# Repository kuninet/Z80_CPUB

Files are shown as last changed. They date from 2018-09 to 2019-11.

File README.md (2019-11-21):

# Z80マイコンCPUボード (KZ80-CPUB)

- SBC8080バスにつながるZ80 CPUボード KZ80-CPUB のデータ類です。
  - CPUボード+[SBC8080 SUBルーズキット](https://vintagechips.wordpress.com/2018/06/23/sbc8080-subルーズキット/)などとのセットでコンピューターとして動作します。(単独では動きません)

- 回路図、部品等の詳しい説明を記載したwikiページは以下になります。
  - https://github.com/kuninet/Z80_CPUB/wiki

## ファイル/ディレクトリ

ファイル/ディレクトリの構成は以下のとおりです

|ファイル/ディレクトリ|概要|
|:--|:--|
|KiCAD/PCB/|基板製造用ガーバーファイル等|
|KiCAD/Z80-CPUB.ods|部品一覧表|
|img/Z80-CPUB.pdf|回路図 PDF版|
|KiCAD/Z80-CPUB*.*|KiCADファイル|

## 注意点

- REV1基板はSBC8080ルーズキットと完全互換ではありません。
  - DMAは行なえません。(#BUSREQ/#BUSACKに対応していない)
  - DMAに伴う#IOR/Wや#MEMR/Wのハイインピーダンス対応を実施していません。

## ライセンス

- 本リポジトリのデータは MIT License のもとで公開します。[LICENSE.txt](LICENSE.txt)を参照して下さい。

## 参照

[電脳伝説:SBC8080ルーズキット](https://vintagechips.wordpress.com/2018/06/24/sbc8080-cpu%E3%83%AB%E3%83%BC%E3%82%BA%E3%82%AD%E3%83%83%E3%83%88/)

[SBC8080 SUBボードへつなぐZ80 CPUボードの作成](https://kuninet.org/2018/08/01/sbc8080-subボードへつなぐz80-cpuボードの作成/)

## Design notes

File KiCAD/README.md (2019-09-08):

# Z80 CPUボード

## 概要

- SBC8080ルーズキットのバス(SBC8080バスと呼称)につながるZ80 CPUボードのKiCADデータです。

## ファイル/ディレクトリ

ファイル/ディレクトリの構成は以下のとおりです

|ファイル/ディレクトリ|概要|
|:--|:--|
|PCB/|基板製造用ガーバーファイル等|
|Z80-CPUB.ods|部品一覧表|
|Z80-CPUB.pdf|回路図 PDF版|
|Z80-CPUB*.*|KiCADファイル|

## 注意点

- REV1基板は、SBC8080ルーズキットと完全互換ではありません。
  - DMAは行なえません。(#BUSREQ/#BUSACKに対応していない)
  - DMAに伴う#IOR/Wや#MEMR/Wのハイインピーダンス対応を実施していません。

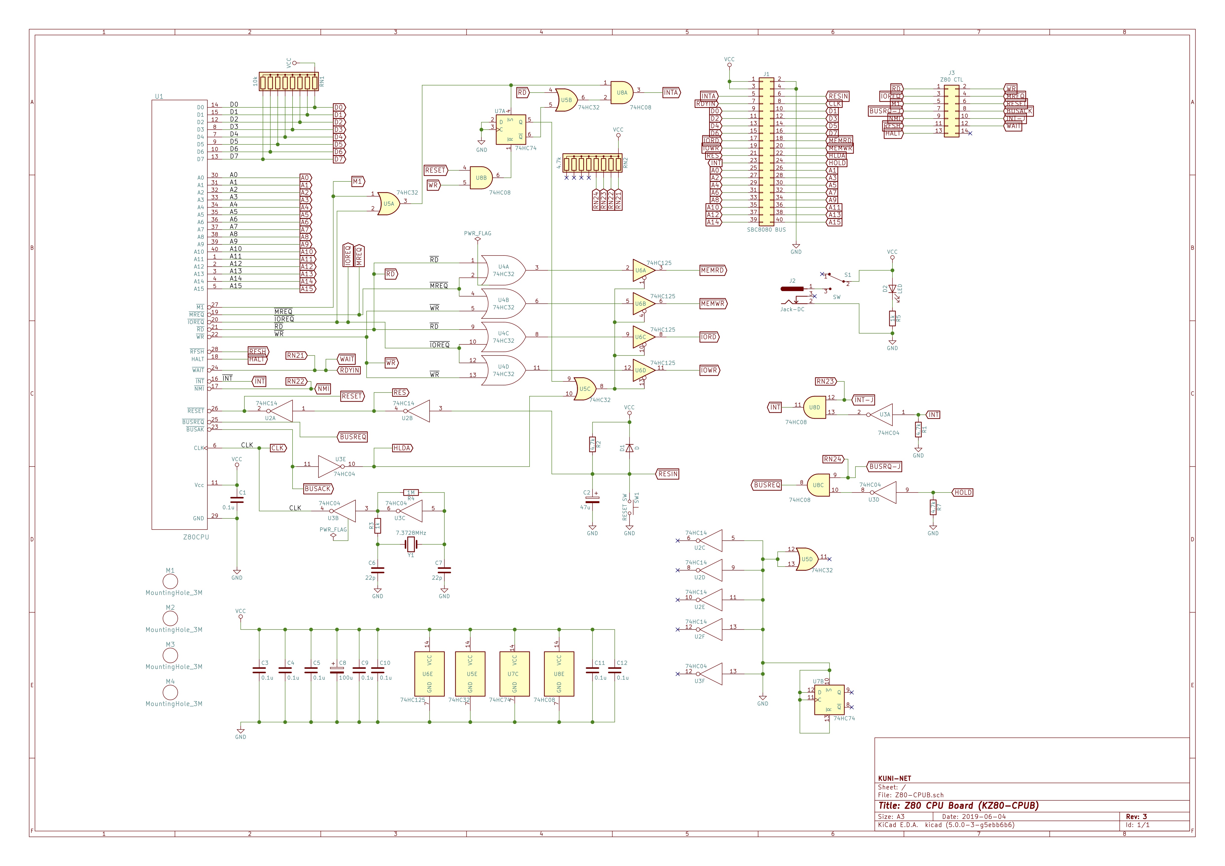
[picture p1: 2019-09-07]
img/Z80-CPUB.jpg

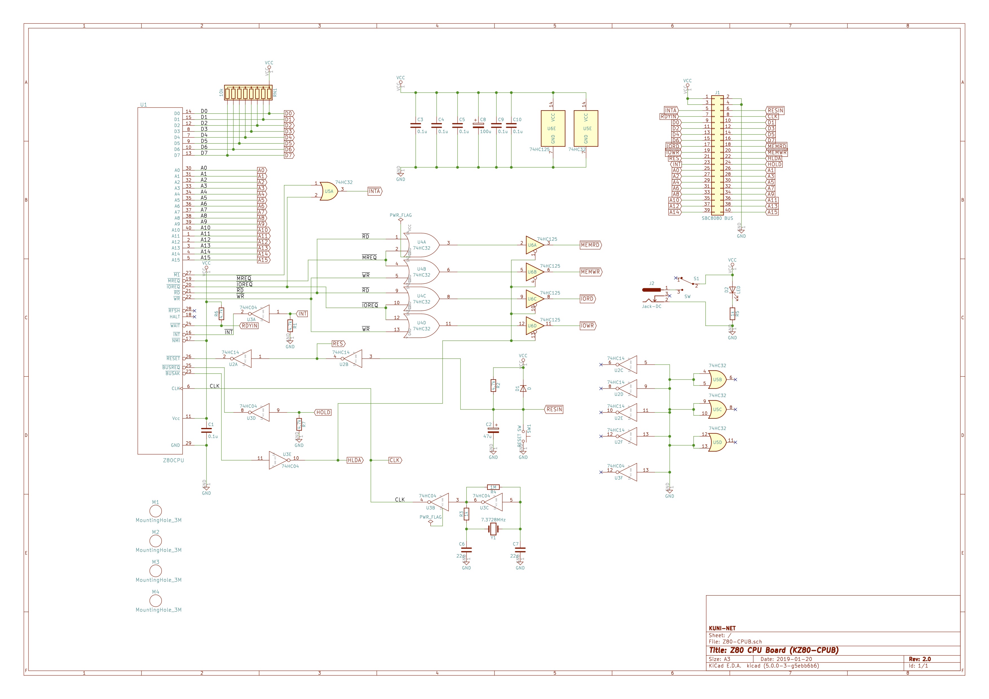
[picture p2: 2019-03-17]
img/Z80-CPUB-REV2.jpg

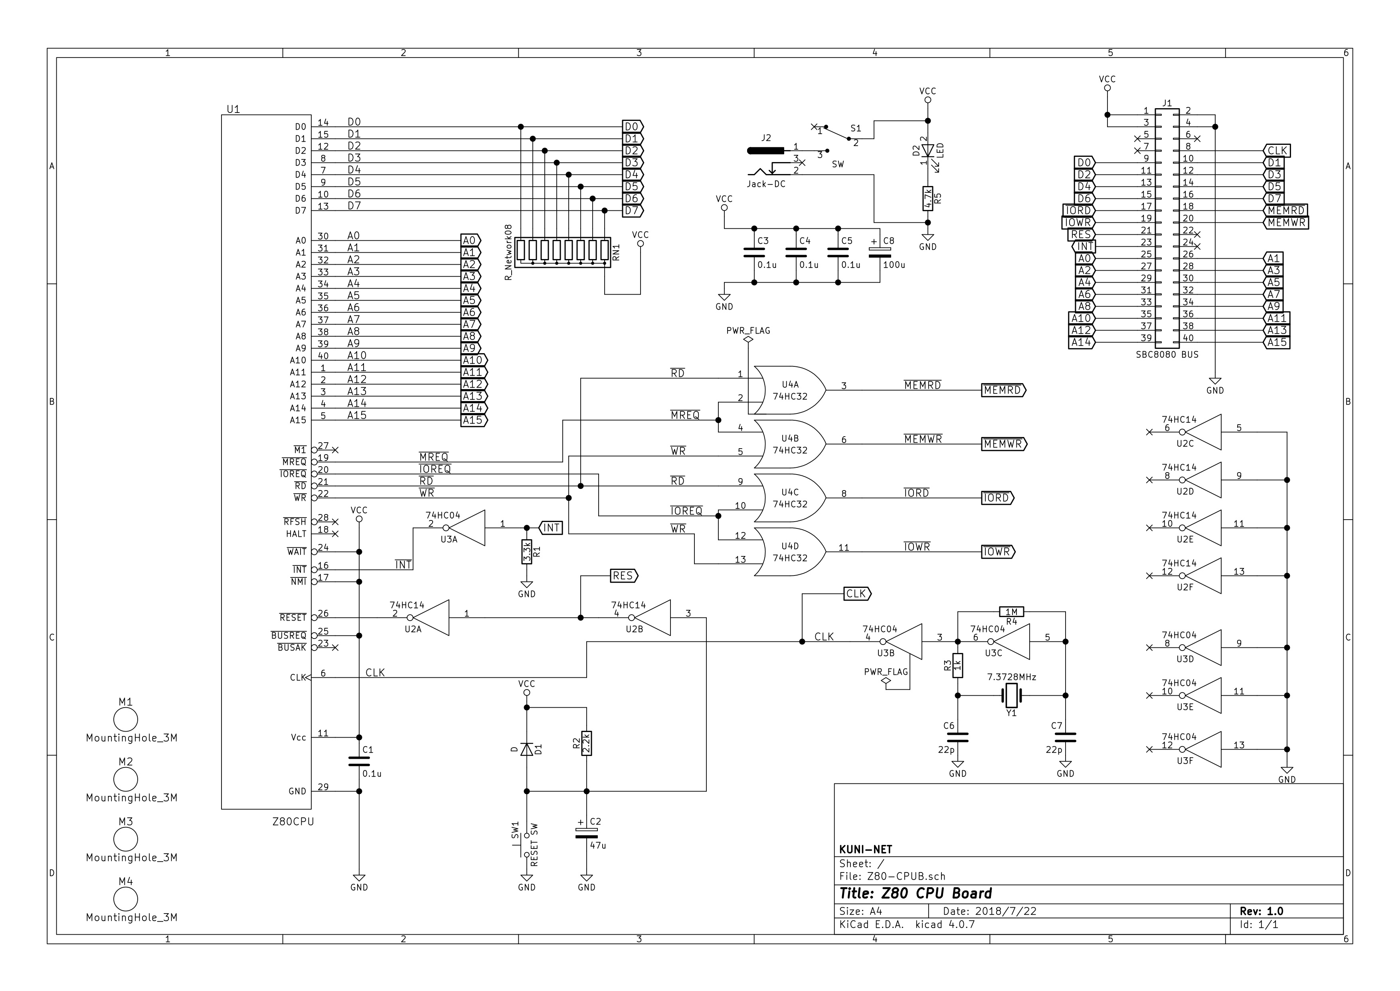
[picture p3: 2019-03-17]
img/Z80-CPUB-REV1.jpg

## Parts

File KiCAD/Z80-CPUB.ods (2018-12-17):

部品番号 | 仕様 | 数量 | 代替可能品 | Footprint
U1 | Z84C0020PEC | 1 | Z80 CMOSタイプ | Housings_DIP:DIP-40_W15.24mm
U2 | 74HC14 | 1 | 74LS14 | Housings_DIP:DIP-14_W7.62mm_Socket
U3 | 74HC04 | 1 | 74HCT04 (CMOS必須) | Housings_DIP:DIP-14_W7.62mm_Socket
U4 | 74HC32 | 1 | 74LS32 | Housings_DIP:DIP-14_W7.62mm_Socket
C1、C3、C4、C5 | 0.1μF | 4 | 積層セラミックコンデンサ | Capacitors_THT:C_Rect_L4.0mm_W2.5mm_P2.50mm
C2 | 47μF | 1 | 電解コンデンサ | Capacitors_THT:CP_Radial_D4.0mm_P2.00mm
C6、C7 | 22p | 2 | 積層セラミックコンデンサ | Capacitors_THT:C_Rect_L4.0mm_W2.5mm_P2.50mm
C8 | 100μF | 1 | 電解コンデンサ | Capacitors_THT:CP_Radial_D7.5mm_P2.50mm
D1 | 1N4148 | 1 | 小電力ダイオード | Diodes_THT:D_DO-41_SOD81_P10.16mm_Horizontal
D2 | OSRRH23133A | 1 | LED | LEDs:LED_D3.0mm
J1 | HIF3FC-40PA-2.54DS | 1 | 40 ピン L 型ボックスヘッダ | Pin_Headers:Pin_Header_Angled_2x20
J2 | MJ-179PH | 1 | 2.1mm φ 平脚DCジャック | Connectors:JACK_ALIM
R1 | 3.3kΩ | 1 | カーボン抵抗 | Resistors_THT:R_Axial_DIN0207_L6.3mm_D2.5mm_P7.62mm_Horizontal
R2 | 2.2kΩ | 1 | カーボン抵抗 | Resistors_THT:R_Axial_DIN0207_L6.3mm_D2.5mm_P7.62mm_Horizontal
R3 | 1kΩ | 1 | カーボン抵抗 | Resistors_THT:R_Axial_DIN0207_L6.3mm_D2.5mm_P7.62mm_Horizontal
R4 | 1MΩ | 1 | カーボン抵抗 | Resistors_THT:R_Axial_DIN0207_L6.3mm_D2.5mm_P7.62mm_Horizontal
R5 | 1kΩ | 1 | カーボン抵抗 | Resistors_THT:R_Axial_DIN0207_L6.3mm_D2.5mm_P7.62mm_Horizontal
RN1 | L091S103LF | 1 | 10kΩ 8素子 9pin 集合抵抗 | Resistors_THT:R_Array_SIP9
S1 | SS-12D00-G5 | 1 | スライドスイッチ | digikey-footprints:Switch_Slide_11.6x4mm_EG1218
SW1 | DTS-6-V | 1 | 小型タクトスイッチ | Buttons_Switches_THT:SW_PUSH_6mm
Y1 | HC49/US | 1 | 水晶振動子 7.3728MHz | Crystals:Crystal_HC49-4H_Vertical

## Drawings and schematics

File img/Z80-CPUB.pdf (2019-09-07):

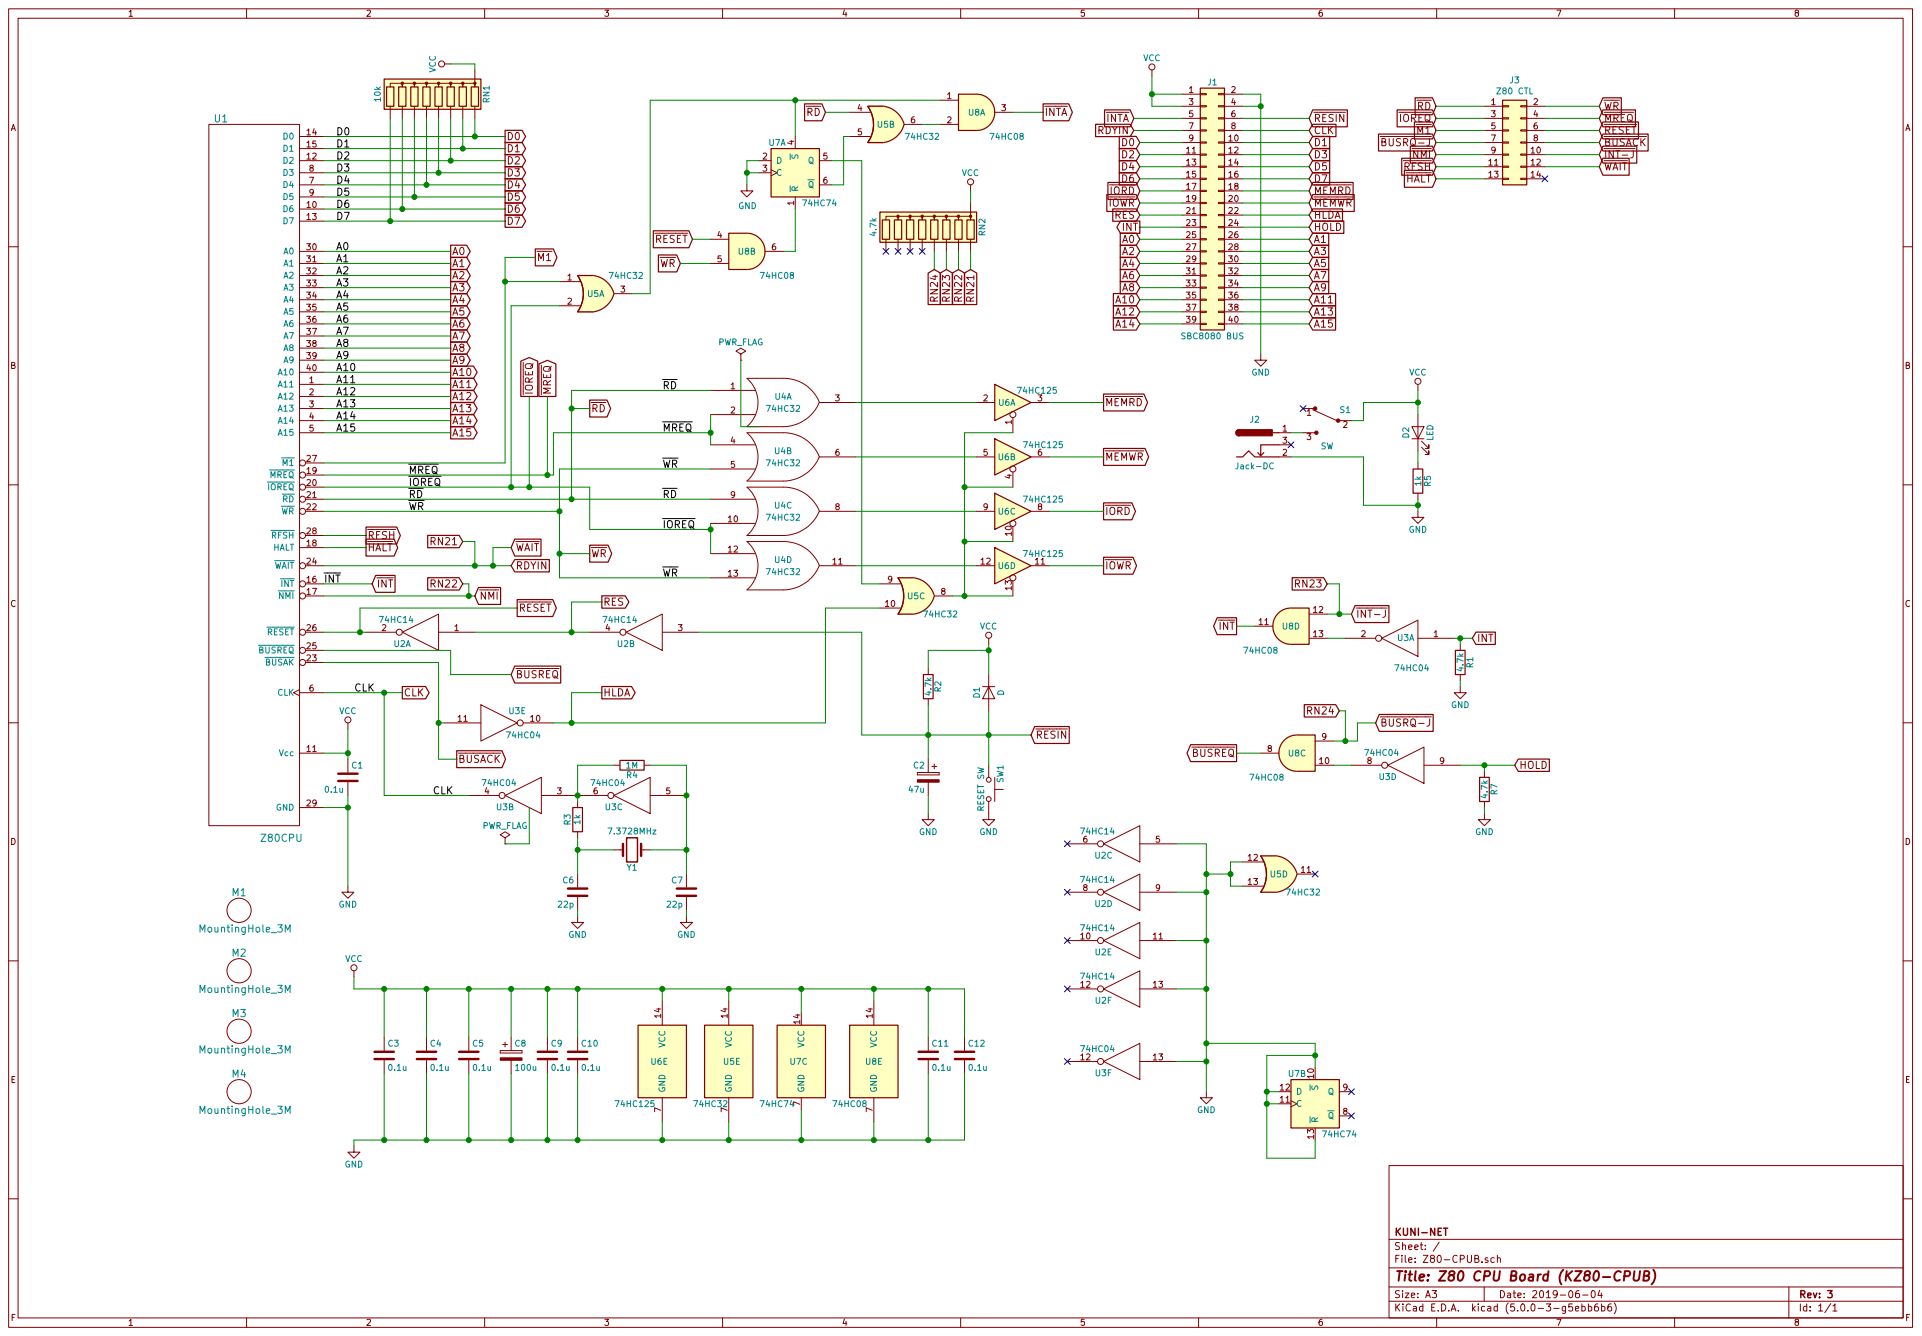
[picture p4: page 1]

Id: 1/1 Title: Z80 CPU Board (KZ80-CPUB) File: Z80-CPUB.sch Sheet: / KUNI-NET

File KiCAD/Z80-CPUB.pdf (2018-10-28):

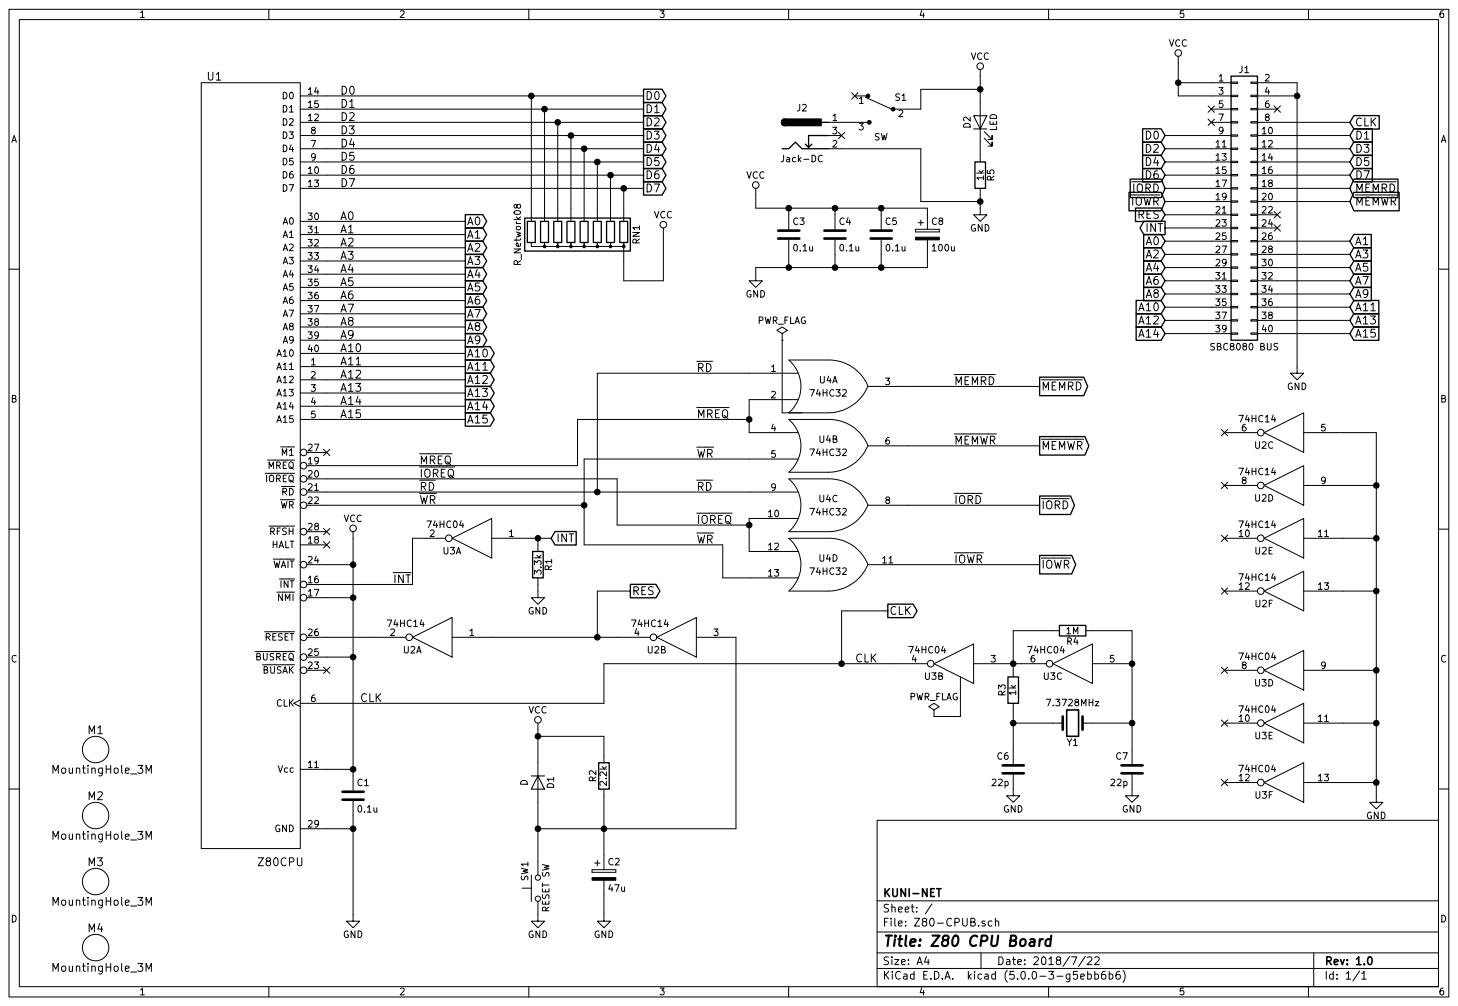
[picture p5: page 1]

File: Z80-CPUB.sch Sheet: / KUNI-NET

Id: 1/1 Title: Z80 CPU Board

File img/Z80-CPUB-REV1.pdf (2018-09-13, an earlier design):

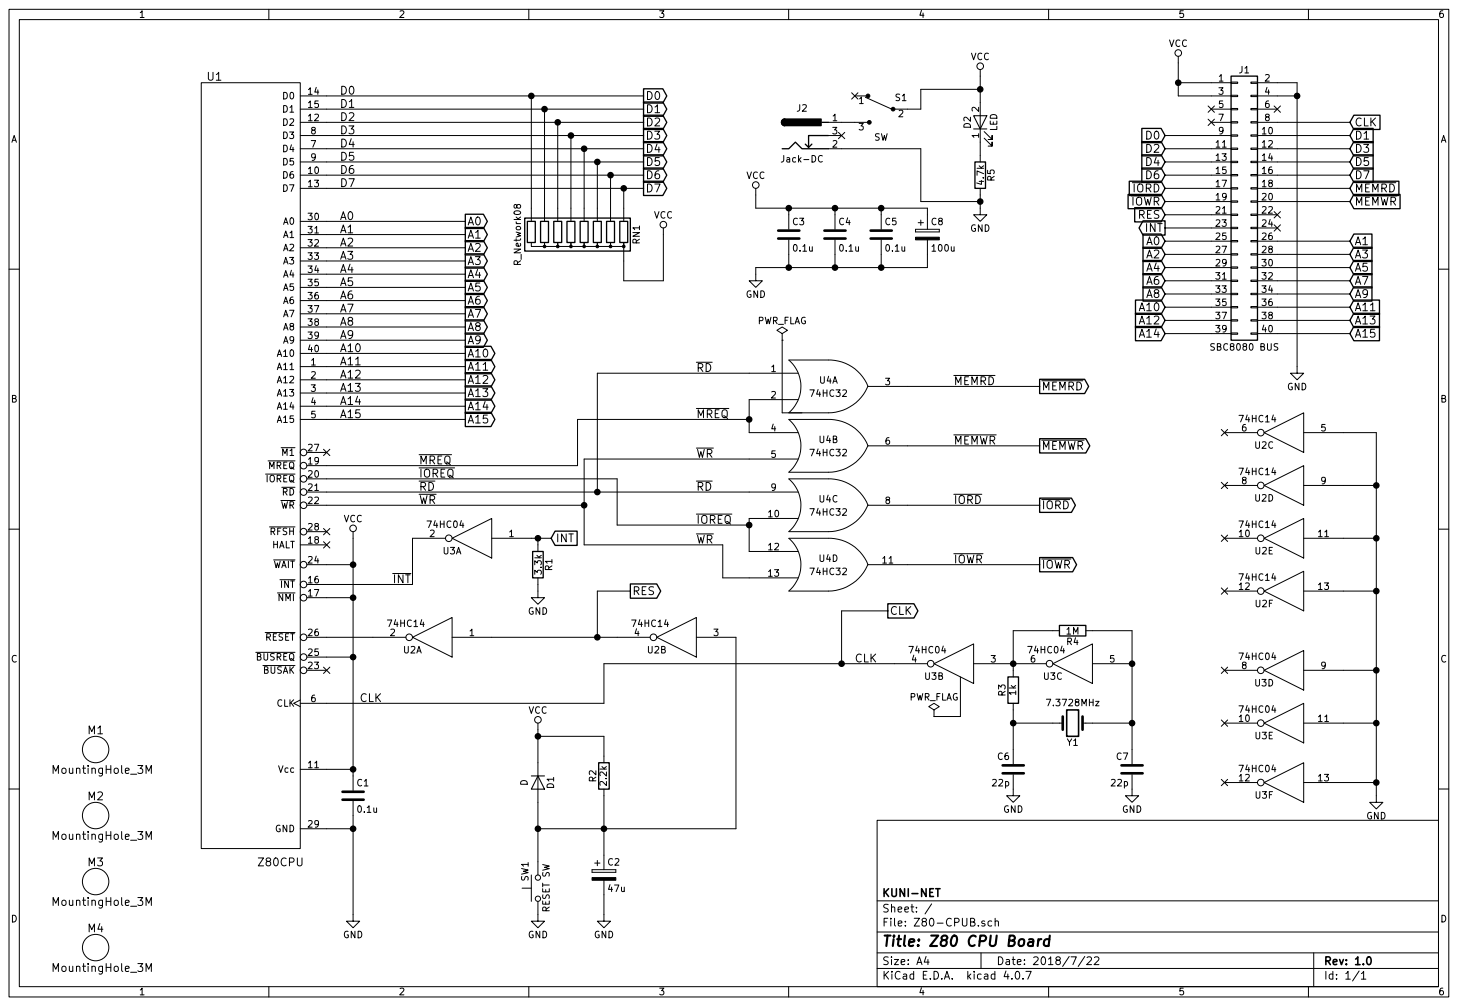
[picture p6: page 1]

File: Z80-CPUB.sch Sheet: / KUNI-NET

Id: 1/1 Title: Z80 CPU Board

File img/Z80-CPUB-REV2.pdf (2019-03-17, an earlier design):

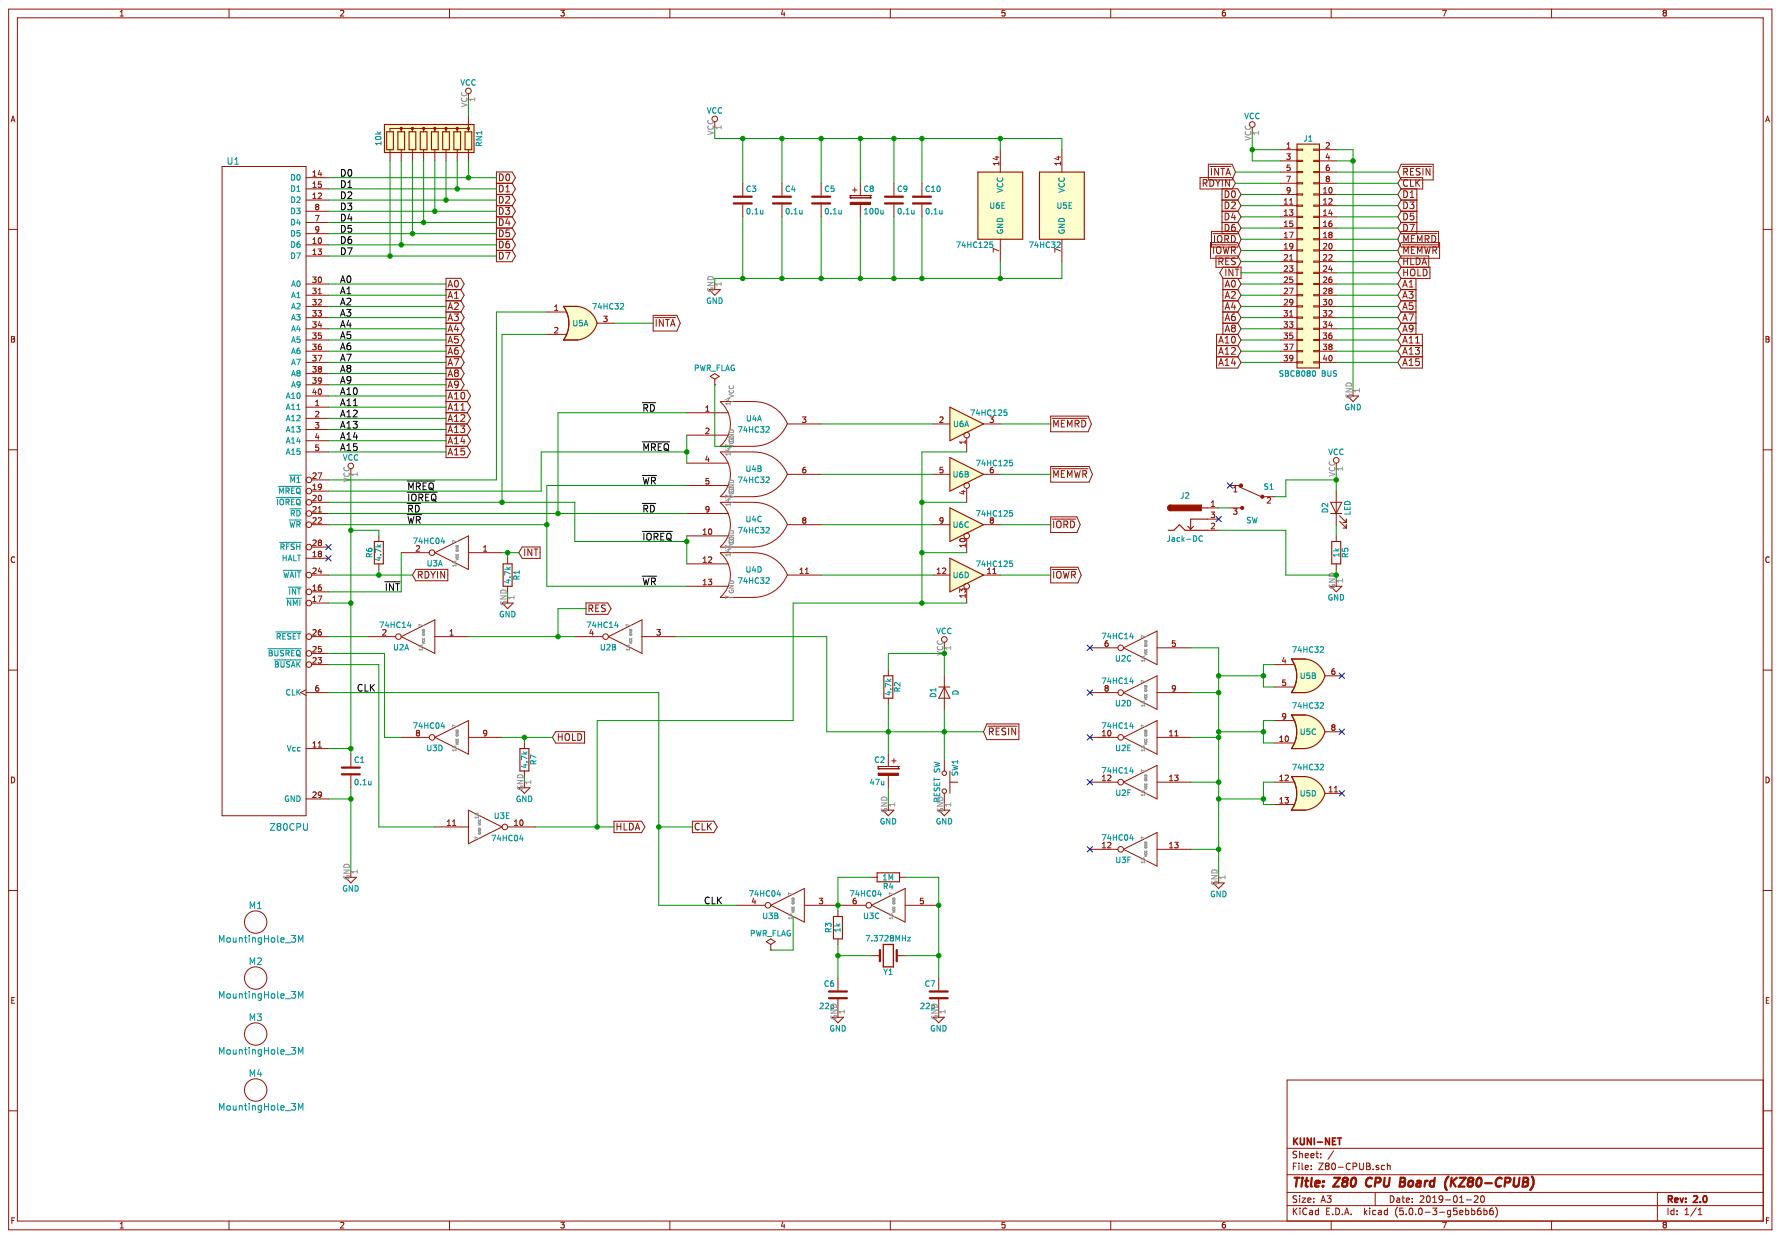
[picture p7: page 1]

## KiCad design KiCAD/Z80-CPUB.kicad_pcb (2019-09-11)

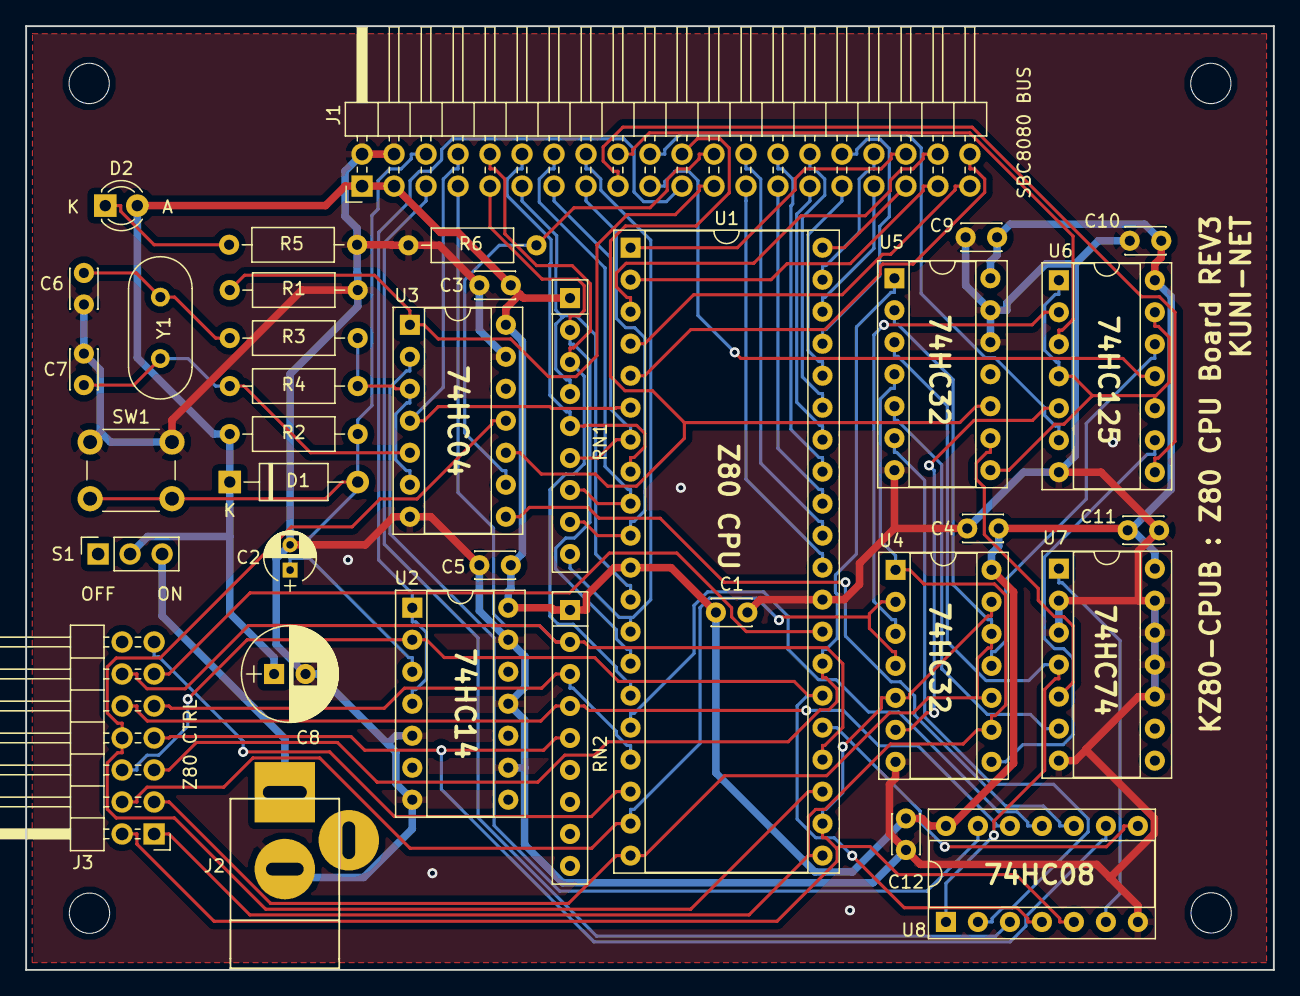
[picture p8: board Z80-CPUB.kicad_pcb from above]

Board: 2 copper layers, 99.1 x 74.9 mm, 40 parts (0 on the bottom side), 69 nets.

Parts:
C1, C3, C4, C5, C9, C10, C11, C12: 0.1u; C_Disc_D3.0mm_W2.0mm_P2.50mm
C2: 47u; CP_Radial_D4.0mm_P2.00mm
C6, C7: 22p; C_Disc_D3.0mm_W2.0mm_P2.50mm
C8: 100u; CP_Radial_D7.5mm_P2.50mm
D1: D; D_A-405_P10.16mm_Horizontal
D2: LED; LED_D3.0mm
J1: SBC8080 BUS; PinHeader_2x20_P2.54mm_Horizontal
J2: Jack-DC; JACK_ALIM
J3: Z80 CTL; PinHeader_2x07_P2.54mm_Horizontal
M1, M2, M3, M4: MountingHole_3M; MountingHole_3.2mm_M3
R1, R2, R6: 4.7k; R_Axial_DIN0207_L6.3mm_D2.5mm_P10.16mm_Horizontal
R3, R5: 1k; R_Axial_DIN0207_L6.3mm_D2.5mm_P10.16mm_Horizontal
R4: 1M; R_Axial_DIN0207_L6.3mm_D2.5mm_P10.16mm_Horizontal
RN1: 10k; R_Array_SIP9
RN2: 4.7k; R_Array_SIP9
S1: SW; PinSocket_1x03_P2.54mm_Vertical
SW1: RESET SW; SW_PUSH_6mm_H4.3mm
U1: Z80CPU; DIP-40_W15.24mm_Socket
U2: 74HC14; DIP-14_W7.62mm_Socket
U3: 74HC04; DIP-14_W7.62mm_Socket
U4, U5: 74HC32; DIP-14_W7.62mm_Socket
U6: 74HC125; DIP-14_W7.62mm_Socket
U7: 74HC74; DIP-14_W7.62mm_Socket
U8: 74HC08; DIP-14_W7.62mm_Socket
Y1: 7.3728MHz; Crystal_HC49-U_Vertical

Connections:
A0: J1.25, U1.30
A1: J1.26, U1.31
A2: J1.27, U1.32
A3: J1.28, U1.33
A4: J1.29, U1.34
A5: J1.30, U1.35
A6: J1.31, U1.36
A7: J1.32, U1.37
A8: J1.33, U1.38
A9: J1.34, U1.39
A10: J1.35, U1.40
A11: J1.36, U1.1
A12: J1.37, U1.2
A13: J1.38, U1.3
A14: J1.39, U1.4
A15: J1.40, U1.5
CLK: J1.8, U1.6, U3.4
D0: J1.9, RN1.2, U1.14
D1: J1.10, RN1.3, U1.15
D2: J1.11, RN1.4, U1.12
D3: J1.12, RN1.5, U1.8
D4: J1.13, RN1.6, U1.7
D5: J1.14, RN1.7, U1.9
D6: J1.15, RN1.8, U1.10
D7: J1.16, RN1.9, U1.13
GND: C1.2, C2.2, C3.2, C4.2, C5.2, C6.2, C7.2, C8.2, C9.2, C10.2, C11.2, C12.2, J1.2, J1.4, J2.2, R1.2, R5.2, R6.2, SW1.1, U1.29, U2.5, U2.7, U2.9, U2.11, U2.13, U3.7, U3.13, U4.7, U5.7, U5.12, U5.13, U6.7, U7.2, U7.3, U7.7, U7.10, U7.11, U7.12, U7.13, U8.7
HLDA: J1.22, U3.10, U5.10
HOLD: J1.24, R6.1, U3.9
INT: J1.23, R1.1, U3.1
unnamed: C6.1, R3.2, Y1.1
unnamed: C7.1, R4.2, U3.5, Y1.2
unnamed: D2.1, R5.1
unnamed: J2.1, S1.3
unnamed: R3.1, R4.1, U3.3, U3.6
unnamed: U3.2, U8.13
unnamed: U3.8, U8.10
unnamed: U4.3, U6.2
unnamed: U4.6, U6.5
unnamed: U4.8, U6.9
unnamed: U4.11, U6.12
unnamed: U5.3, U7.4, U8.1
unnamed: U5.5, U7.6
unnamed: U5.6, U8.2
unnamed: U5.8, U6.1, U6.4, U6.10, U6.13
unnamed: U5.9, U7.5
unnamed: U7.1, U8.6
RDYIN: J1.7, J3.12, RN2.2, U1.24
RES: J1.21, U2.1, U2.4
RN22: J3.9, RN2.3, U1.17
RN23: J3.10, RN2.4, U8.12
RN24: J3.7, RN2.5, U8.9
VCC: C1.1, C3.1, C4.1, C5.1, C8.1, C9.1, C10.1, C11.1, C12.1, D1.1, D2.2, J1.1, J1.3, R2.1, RN1.1, RN2.1, S1.2, U1.11, U2.14, U3.14, U4.14, U5.14, U6.14, U7.14, U8.14
~BUSACK: J3.8, U1.23, U3.11
~BUSREQ: U1.25, U8.8
~HALT: J3.13, U1.18
~INT: U1.16, U8.11
~INTA: J1.5, U8.3
~IORD: J1.17, U6.8
~IOREQ: J3.3, U1.20, U4.10, U4.12, U5.2
~IOWR: J1.19, U6.11
~M1: J3.5, U1.27, U5.1
~MEMRD: J1.18, U6.3
~MEMWR: J1.20, U6.6
~MREQ: J3.4, U1.19, U4.2, U4.4
~RD: J3.1, U1.21, U4.1, U4.9, U5.4
~RESET: J3.6, U1.26, U2.2, U8.4
~RESIN: C2.1, D1.2, J1.6, R2.2, SW1.2, U2.3
~RFSH: J3.11, U1.28
~WR: J3.2, U1.22, U4.5, U4.13, U8.5

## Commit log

2018-09-13 init commit
    [Z80-CPUB.dsn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]
2018-09-13 ディレクトリIOB/とRAMB/追加
2018-09-13 CPUボードREADME修正
2018-09-13 メモリーボードREADME追加
2018-09-30 ディレクトリレイアウト変更
    [Z80-CPUB.dsn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]
2018-10-07 ボード命名&シルク修正
    [Z80-CPUB-2018-10-02-22-46-50.sch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]
2018-10-08 r1.1 最終確認
    [Z80-CPUB.kicad_pcb, Z80-CPUB.sch]
2018-10-08 水晶発信のため74HC04はCMOS必須と明記
    [Z80-CPUB.ods]
2018-10-17 PDF差し替え
2018-10-28 部品リストで、74HC04の代替品を修正
    [Z80-CPUB.ods]
2018-12-17 R5 抵抗値変更
    [Z80-CPUB.ods]
2019-03-17 REV2 回路図、製造データ出力
    [Z80-CPUB.dsn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]
2019-03-17 旧回路図(REV1) 別ファイルへ
2019-03-23 REV2.1検討開始 回路図、パターン変更
    [Z80-CPUB.dsn, Z80-CPUB.kicad_pcb, Z80-CPUB.sch]
2019-09-07 REV3基板パターン、ガーバーデータ出力
    [Z80-CPUB.dsn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]
2019-09-07 回路図 REV3版出力
2019-09-08 シルク見直し、ガーバーデータ出力
    [Z80-CPUB.GBL, Z80-CPUB.GBO, Z80-CPUB.GBS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]
2019-09-11 背面シルク追加、ガーバーデータ再出力
    [Z80-CPUB.kicad_pcb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]
